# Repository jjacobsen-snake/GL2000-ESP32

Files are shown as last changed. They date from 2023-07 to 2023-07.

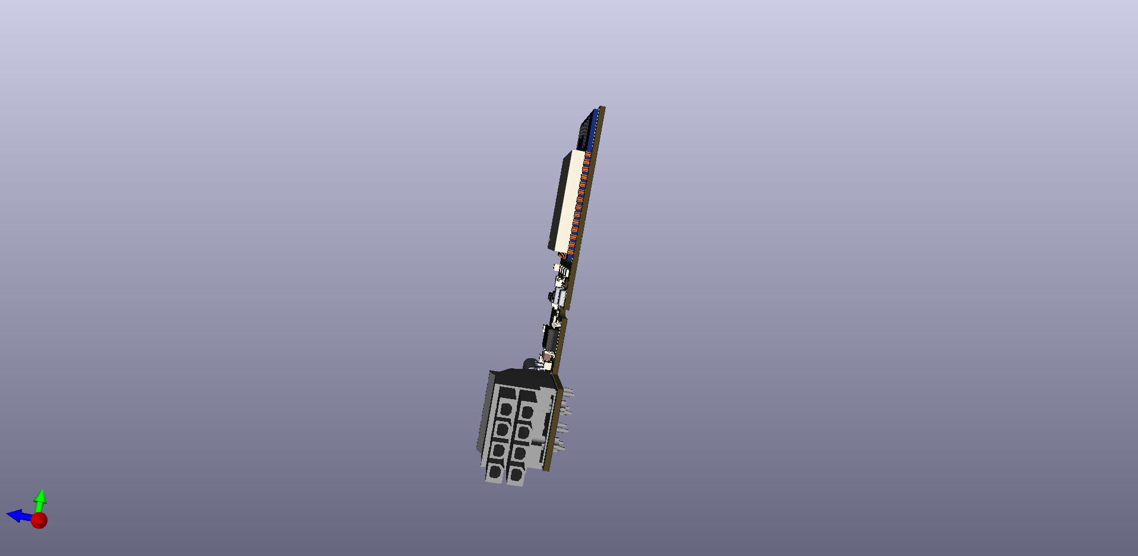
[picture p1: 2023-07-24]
3D-Renderings/v1.01/GL2000-ESP32-4.jpg

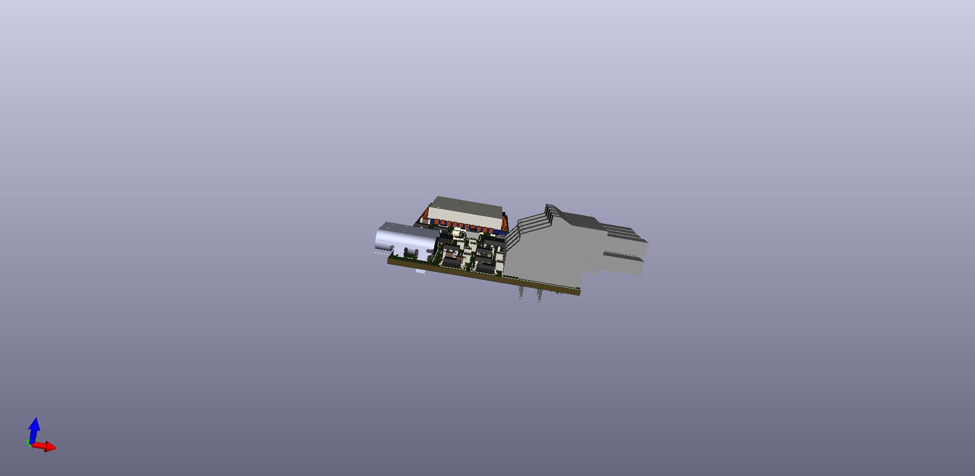
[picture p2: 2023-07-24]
3D-Renderings/v1.01/GL2000-ESP32-1.jpg

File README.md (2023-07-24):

# GL2000-ESP32
GL2000 ESP32 WiFi Module

Schematic and PCB designed by me, surrounding [netmindz project](https://github.com/netmindz/balboa_GL_ML_spa_control)

## Pin configuration:
* GPIO 0 - BOOT Button
* GPIO 1 - TxD / USB via FT230XQ
* GPIO 2 - Status LED
* GPIO 3 - RxD / USB via FT230XQ
* GPIO 4 - RD / MAX485E RD
* GPIO 13 - (Pin 4 - Digital pin) Via level shifter
* GPIO 14 - (Pin 5 - Main panel port selector) Via level shifter
* GPIO 16 - RxD2 / MAX485E Tx
* GPIO 17 - TxD2 / MAX485E Rx
* GPIO 21 - SDA / I2C used for BME280, BME680 or SHT45
* GPIO 22 - SCL / I2C used for BME280, BME680 or SHT45

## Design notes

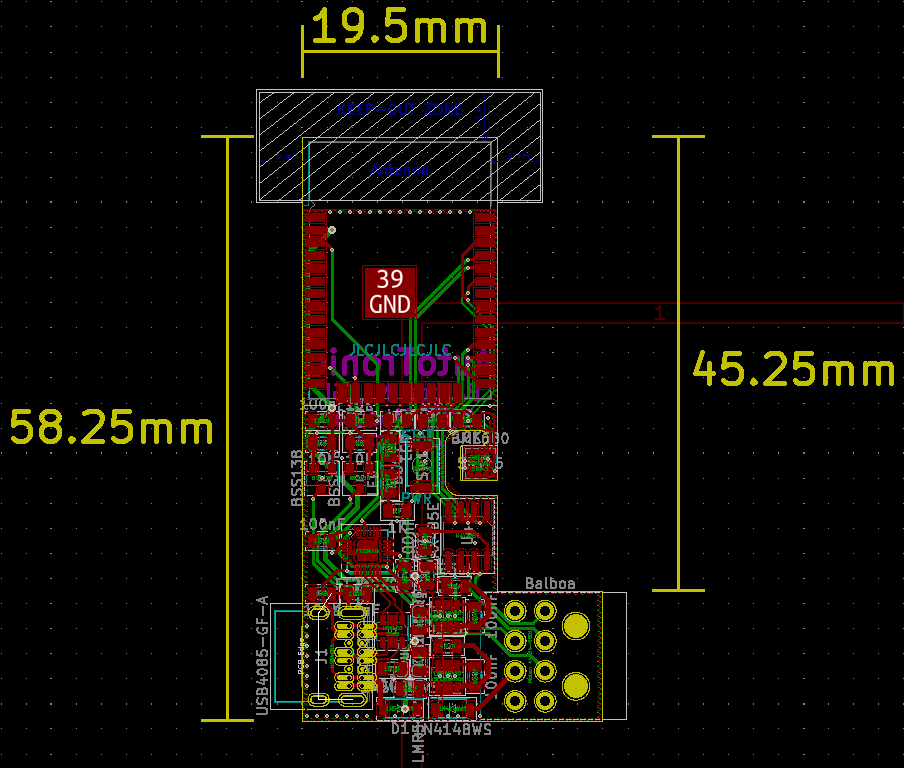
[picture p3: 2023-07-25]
PCB-Size.png

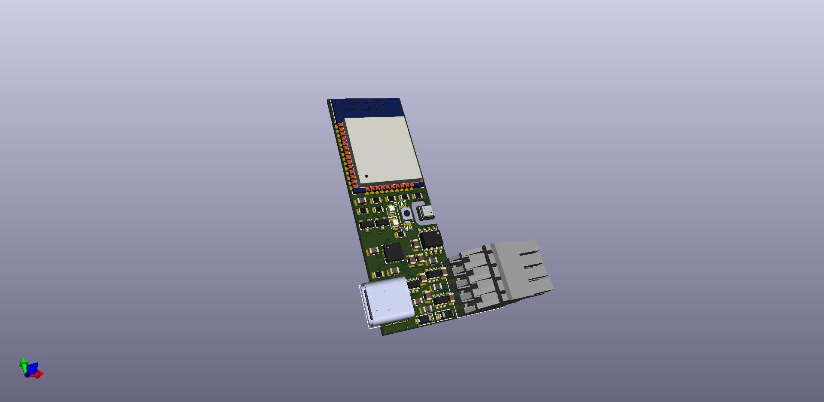
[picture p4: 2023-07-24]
3D-Renderings/v1.01/GL2000-ESP32-3.jpg

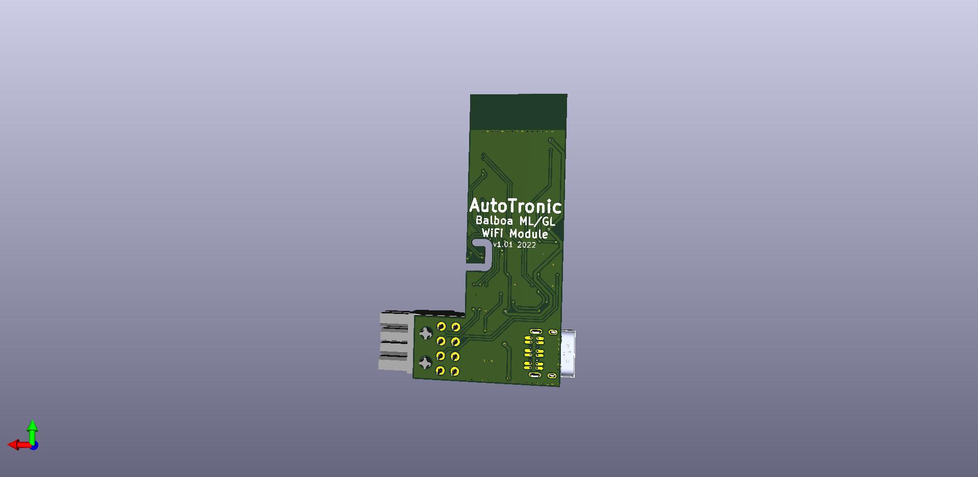
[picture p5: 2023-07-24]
3D-Renderings/v1.01/GL2000-ESP32-5.jpg

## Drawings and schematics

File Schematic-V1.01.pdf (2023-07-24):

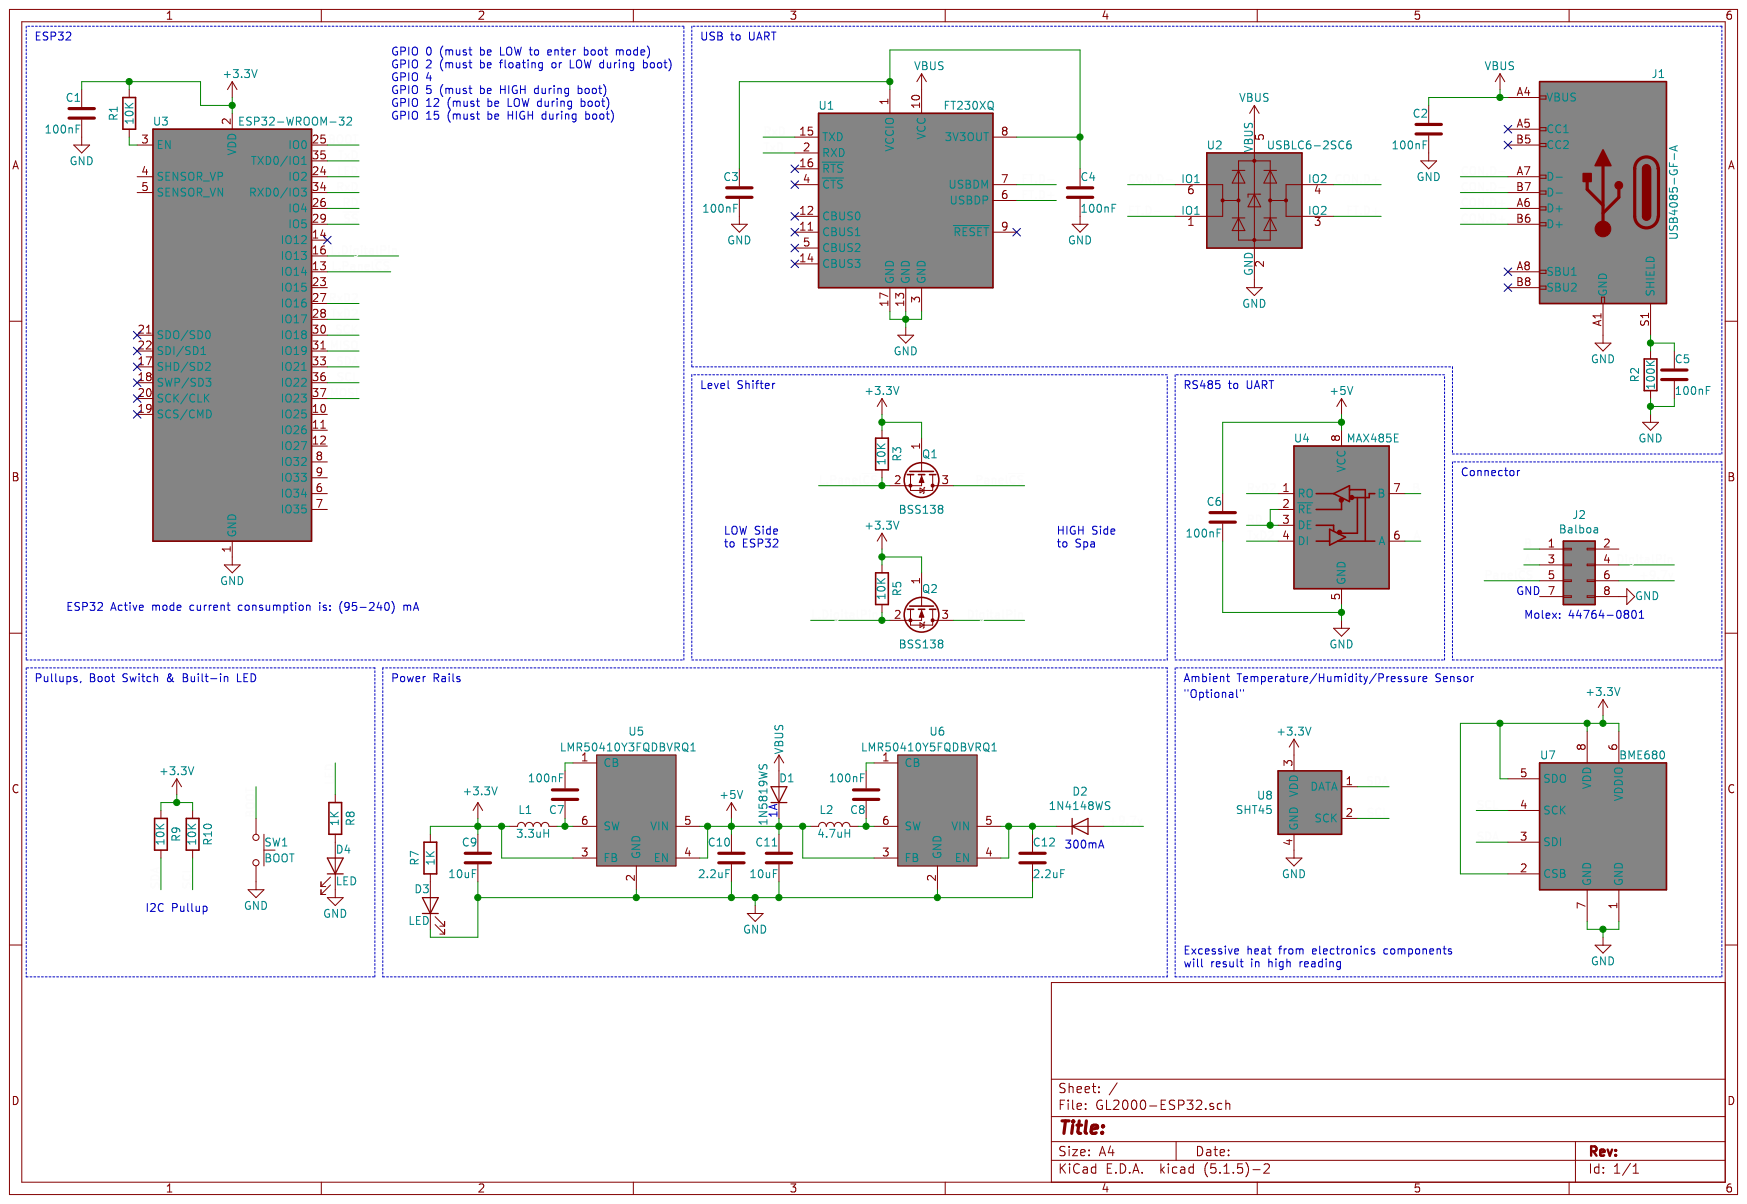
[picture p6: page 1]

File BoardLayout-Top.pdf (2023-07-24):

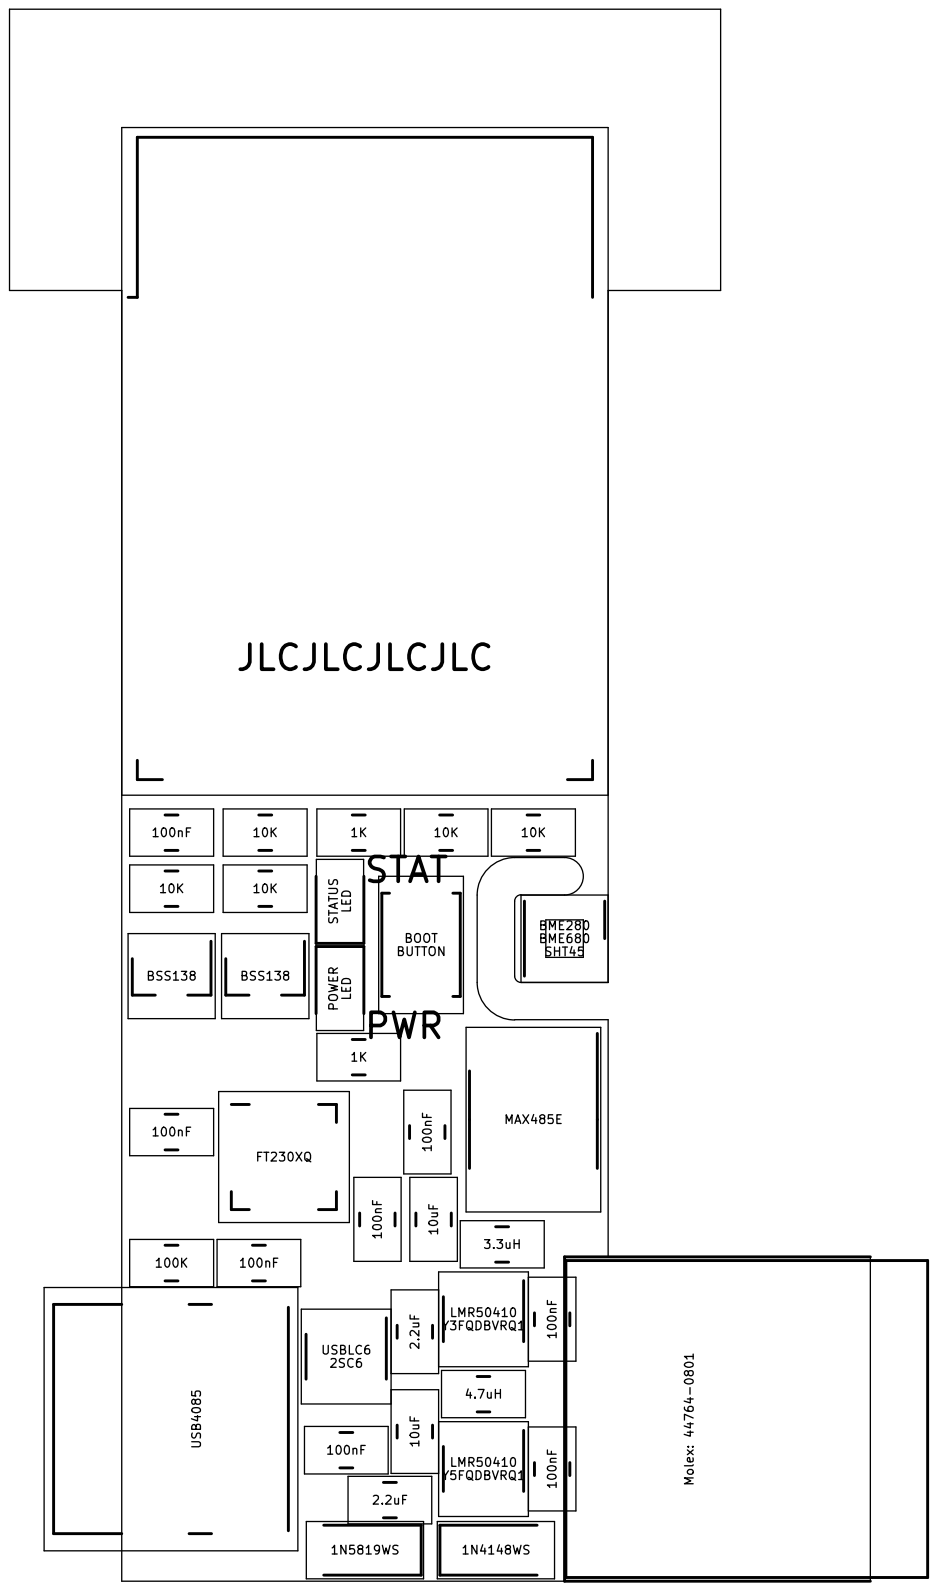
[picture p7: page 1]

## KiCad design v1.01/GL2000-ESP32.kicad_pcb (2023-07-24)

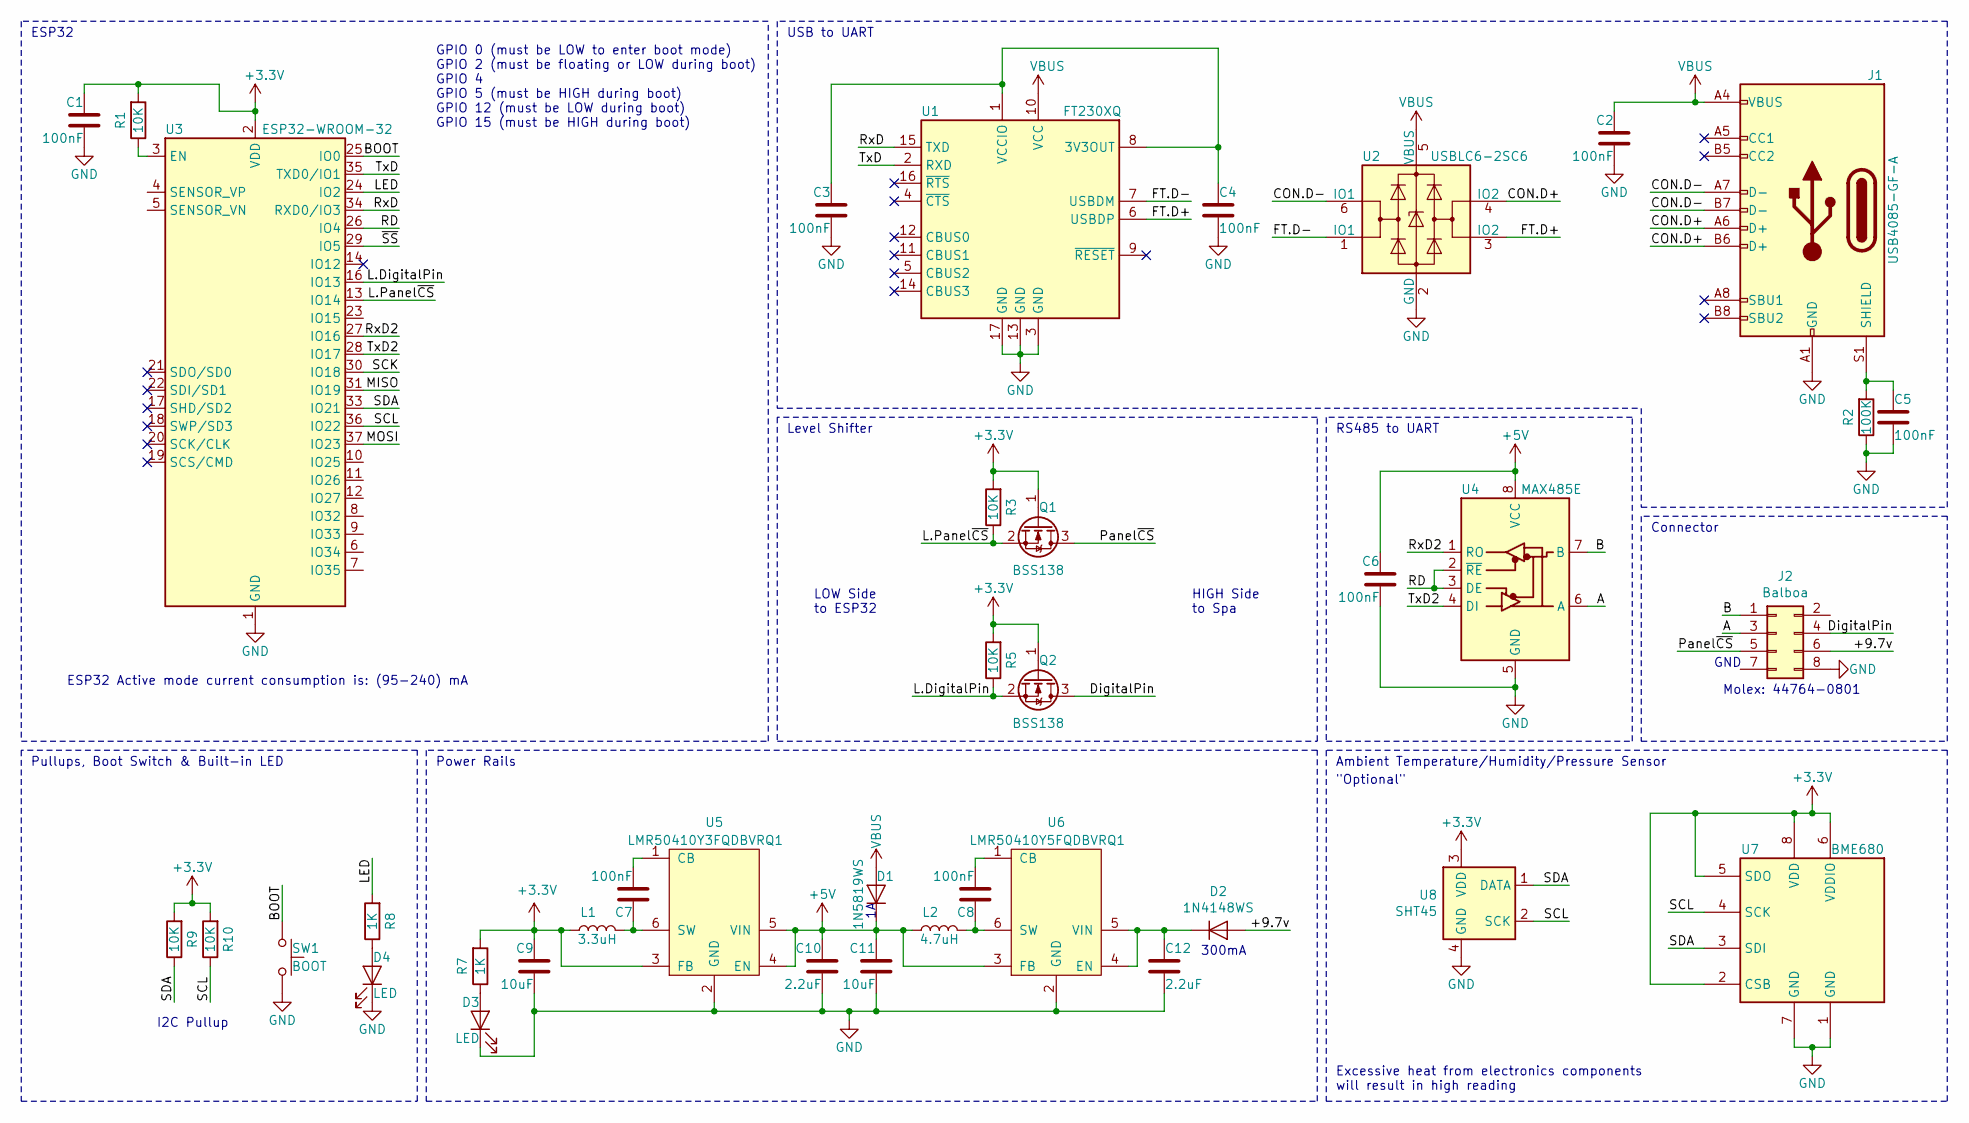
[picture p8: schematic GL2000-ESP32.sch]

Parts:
C1, C2, C3, C4, C5, C6, C7, C8: 100nF; C_0805_2012Metric
C9, C11: 10uF; C_0805_2012Metric
C10, C12: 2.2uF; C_0805_2012Metric
D1: 1N5819WS; D_SOD-123
D2: 1N4148WS; D_SOD-123
D3, D4: LED; LED_0805_2012Metric
J1: USB4085-GF-A; USB_C_Receptacle_GCT_USB4085_USB2.0
J2: Balboa; Molex_MicroFit-3.0_44764-0801
L1: 3.3uH; L_0805_2012Metric
L2: 4.7uH; L_0805_2012Metric
Q1, Q2: BSS138; SOT-23
R1, R3, R5, R9, R10: 10K; R_0805_2012Metric
R2: 100K; R_0805_2012Metric
R7, R8: 1K; R_0805_2012Metric
SW1: BOOT; SW_Push_SPST_NO_Alps_SKRK
U1: FT230XQ; QFN-16-1EP_4x4mm_P0.65mm_EP2.1x2.1mm
U2: USBLC6-2SC6; SOT-23-6
U3: ESP32-WROOM-32
U4: MAX485E; SOIC-8_3.9x4.9mm_P1.27mm
U5: LMR50410Y3FQDBVRQ1; SOT-23-6
U6: LMR50410Y5FQDBVRQ1; SOT-23-6
U7: BME680; Bosch_LGA-8_3x3mm_P0.8mm_ClockwisePinNumbering
U8: SHT45; SHT4x

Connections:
+3V3: C1.1, C9.1, L1.2, Q1.1 (G), Q2.1 (G), R1.2, R3.2, R5.2, R7.2, R9.2, R10.2, U3.2 (VDD), U5.3 (FB), U7.2 (CSB), U7.5 (SDO), U7.6 (VDDIO), U7.8 (VDD), U8.3 (VDD)
+5V: C6.1, C10.1, C11.1, D1.1 (K), L2.2, U4.8 (VCC), U5.4 (EN), U5.5 (VIN), U6.3 (FB)
/+9.7v: D2.2 (A), J2.6
/A: J2.3, U4.6 (A)
/B: J2.1, U4.7 (B)
/BOOT: SW1.1, U3.25 (IO0)
/CON.D+: J1.A6 (D+), J1.B6 (D+), U2.4 (IO2)
/CON.D-: J1.A7 (D-), J1.B7 (D-), U2.6 (IO1)
/DigitalPin: J2.4, Q2.3 (D)
/FT.D+: U1.6 (USBDP), U2.3 (IO2)
/FT.D-: U1.7 (USBDM), U2.1 (IO1)
/L.DigitalPin: Q2.2 (S), R5.1, U3.16 (IO13)
/L.Panel~CS: Q1.2 (S), R3.1, U3.13 (IO14)
/LED: R8.2, U3.24 (IO2)
/MISO: U3.31 (IO19)
/MOSI: U3.37 (IO23)
/Panel~CS: J2.5, Q1.3 (D)
/RD: U3.26 (IO4), U4.2 (~RE), U4.3 (DE)
/RxD: U1.15 (TXD), U3.34 (RXD0/IO3)
/RxD2: U3.27 (IO16), U4.1 (RO)
/SCK: U3.30 (IO18)
/SCL: R10.1, U3.36 (IO22), U7.4 (SCK), U8.2 (SCK)
/SDA: R9.1, U3.33 (IO21), U7.3 (SDI), U8.1 (DATA)
/TxD: U1.2 (RXD), U3.35 (TXD0/IO1)
/TxD2: U3.28 (IO17), U4.4 (DI)
/~SS: U3.29 (IO5)
GND: C1.2, C2.2, C3.2, C4.2, C5.2, C6.2, C9.2, C10.2, C11.2, C12.2, D3.1 (K), D4.1 (K), J1.A1 (GND), J1.A12 (GND), J1.B1 (GND), J1.B12 (GND), J2.8, R2.1, SW1.2, U1.3 (GND), U1.13 (GND), U1.17 (GND), U2.2 (GND), U3.1 (GND), U3.15 (GND), U3.38 (GND), U3.39 (GND), U4.5 (GND), U5.2 (GND), U6.2 (GND), U7.1 (GND), U7.7 (GND), U8.4 (GND)
unnamed: C3.1, C4.1, U1.1 (VCCIO), U1.8 (3V3OUT)
unnamed: C5.1, J1.S1 (SHIELD), R2.2
unnamed: C7.1, L1.1, U5.6 (SW)
unnamed: C7.2, U5.1 (CB)
unnamed: C8.1, L2.1, U6.6 (SW)
unnamed: C8.2, U6.1 (CB)
unnamed: C12.1, D2.1 (K), U6.4 (EN), U6.5 (VIN)
unnamed: D3.2 (A), R7.1
unnamed: D4.2 (A), R8.1
unnamed: R1.1, U3.3 (EN)
VBUS: C2.1, D1.2 (A), J1.A4 (VBUS), J1.A9 (VBUS), J1.B4 (VBUS), J1.B9 (VBUS), U1.10 (VCC), U2.5 (VBUS)

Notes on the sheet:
GND
USB to UART
Level Shifter
RS485 to UART
Connector
Ambient Temperature/Humidity/Pressure Sensor
Power Rails
ESP32
Pullups, Boot Switch & Built-in LED
"Optional"
300mA
Molex: 44764-0801
ESP32 Active mode current consumption is: (95-240) mA
GPIO 0 (must be LOW to enter boot mode) GPIO 2 (must be floating or LOW during boot) GPIO 4 GPIO 5 (must be HIGH during boot) GPIO 12 (must be LOW during boot) GPIO 15 (must be HIGH during boot)
I2C Pullup
HIGH Side to Spa
LOW Side to ESP32
Excessive heat from electronics components will result in high reading

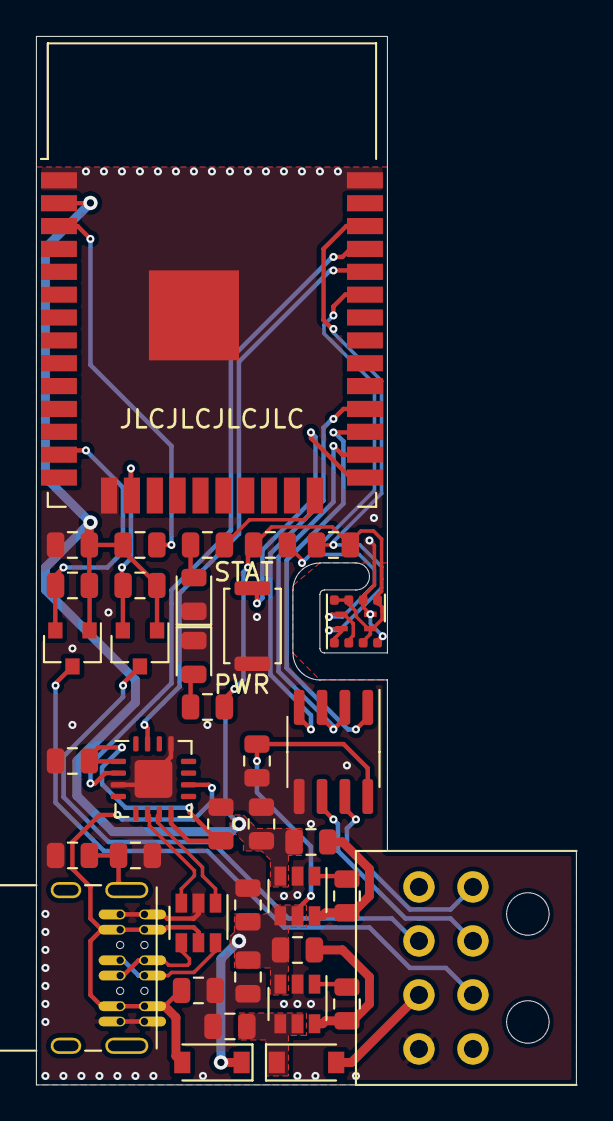
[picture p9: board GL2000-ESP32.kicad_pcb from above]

Board: 2 copper layers, 30.0 x 58.2 mm, 39 parts (0 on the bottom side), 34 nets.

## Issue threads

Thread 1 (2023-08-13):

Missing components?

netmindz, 2023-08-13:
When I try and upload the project to JLCPCB it imports the PCB itself from the zip, but it doesn't appear to pick up the components properly as if i choose the assembly option there are no components. Is this user error or something missing from the zip?

netmindz, 2023-08-13:
Ah, after confirm and login it's now asking for the BOM and CPL files

netmindz, 2023-08-13:
Would be great to have as a project with their EasyEDA setup, ready to just order.  It imports your kicad files more or less ok, does warn about some nets. It can build a BOM but when I go to select the right components there are a few it's not sure about.

If you can create a username with JLPCB the I can share where I've got to so far with setting up as project with https://oshwlab.com/

netmindz, 2023-08-13:
https://jlcpcb.com/help/article/81-How-to-generate-the-BOM-and-Centroid-file-from-KiCAD might also be helpful

netmindz, 2023-10-21:
Hello?
